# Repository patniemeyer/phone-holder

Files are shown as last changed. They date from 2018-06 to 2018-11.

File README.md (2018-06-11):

# OpenSCAD Tesla Model 3 Cup holder mount for iPhone X
_Pat Niemeyer (pat@pat.net), https://github.com/patniemeyer/phone-holder)

<table>
  <tr>
    <th>
      
    </th>
    <th>
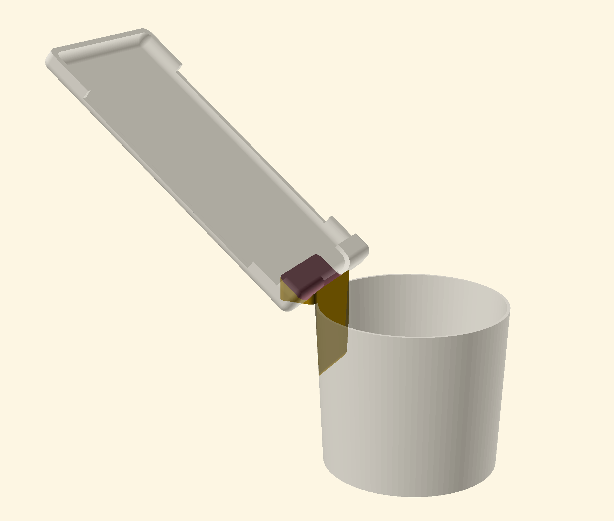
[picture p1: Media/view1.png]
      
    </th>
  </tr>
</table>

This is a simple OpenSCAD phone holder that mounts an iPhone X in a Tesla Model cup holder.

## Warning: 
The rubber lining of the cup holder and the plastic surface of the center console are easily scratched.
If you print this phone holder yourself please go over it with some sandpaper to remove any unexpected bumps or
rough spots before using it in your car!  

## Printing the parts 

The STL folder contains the STL cup-holder.stl file along with some other phone mounts from this project.

I was able to print this easily with only supports on the center connector area as shown here:
</p>
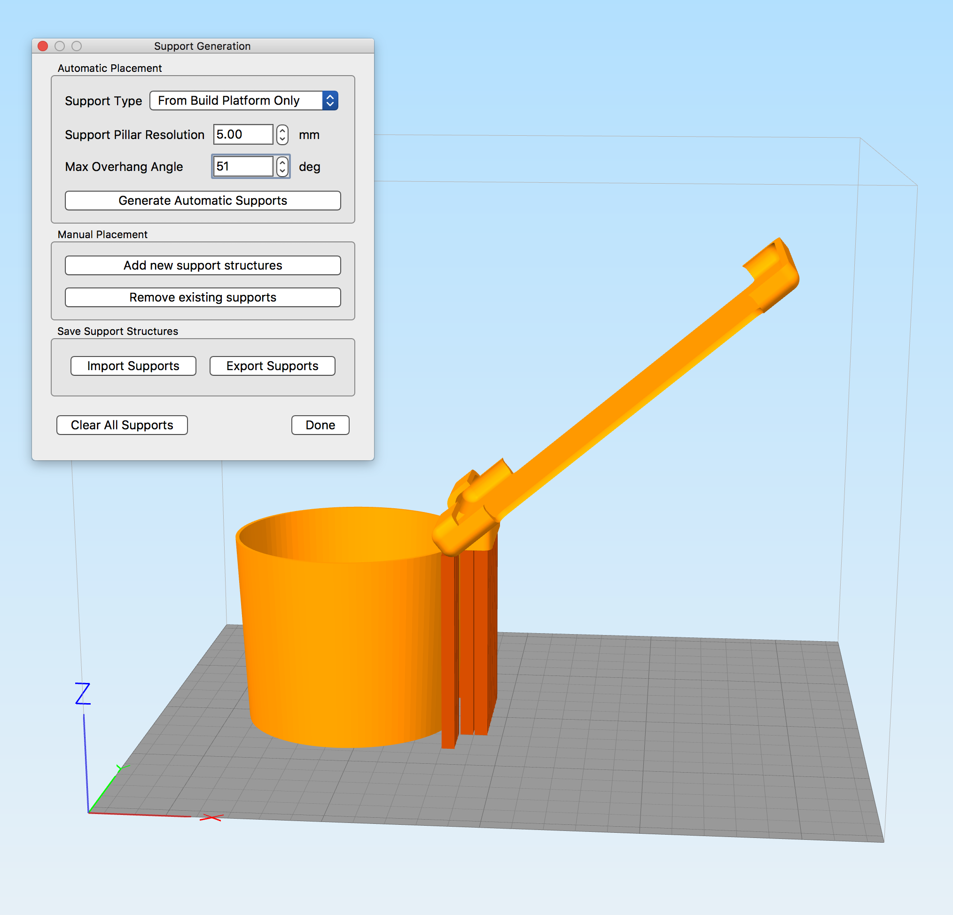
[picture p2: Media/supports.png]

</p>

An obvious improvement would be to make this printable in two sections for those who cannot print it in a single pass.

## Issues

The first version of this was thinner and I found that the PLA softened when the car was in direct sunlight, causing 
it to droop a bit.  I will continue to refine this as I see how the new one holds up.  If you wish to experiment, just
change the `phone_thickness` parameter in the scad file.

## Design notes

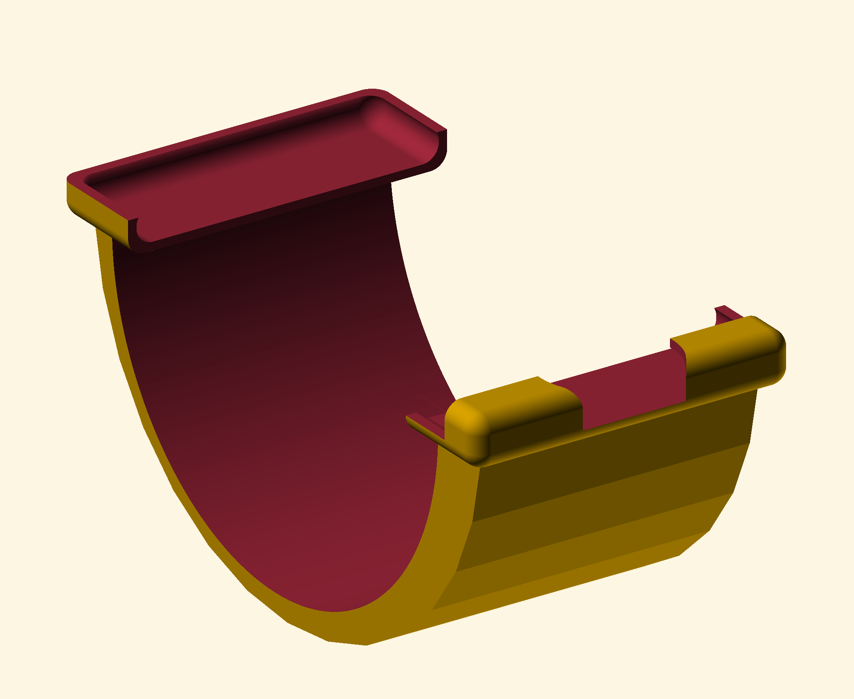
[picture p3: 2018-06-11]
Media/Screen Shot 2018-02-23 at 7.23.17 PM.png

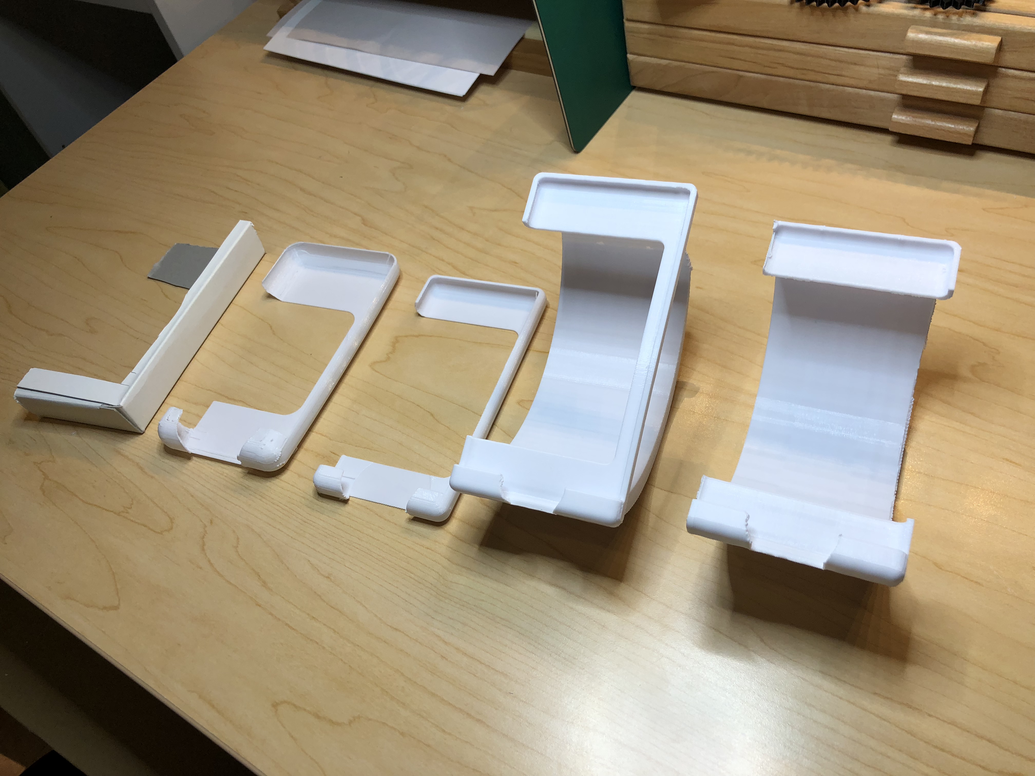
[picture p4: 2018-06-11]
Media/prototypes1.jpg

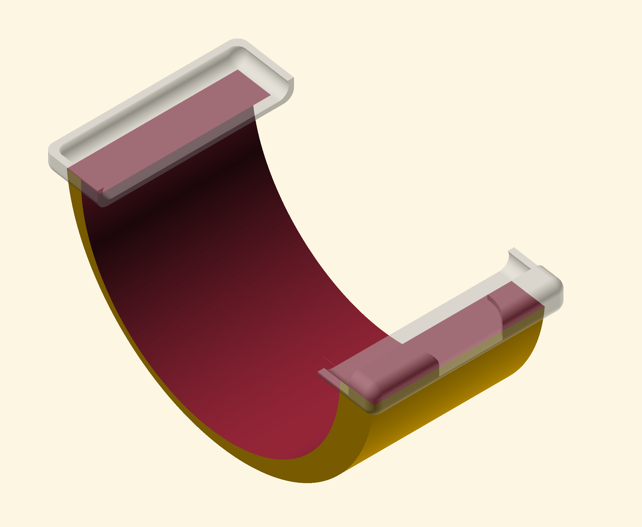
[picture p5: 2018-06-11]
Media/curved1.png

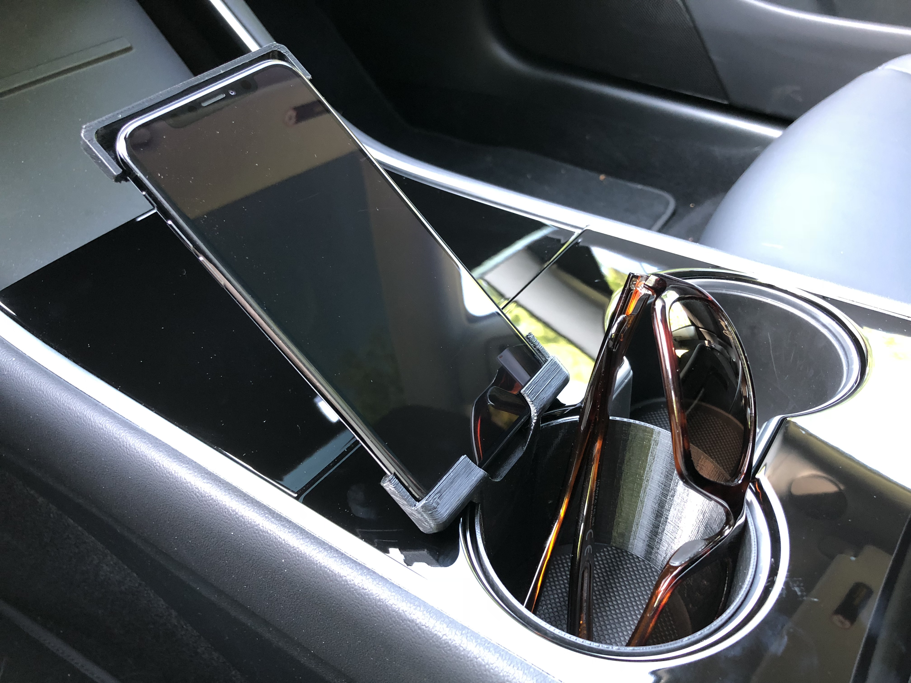
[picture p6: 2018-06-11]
Media/phone-holder-car.jpg

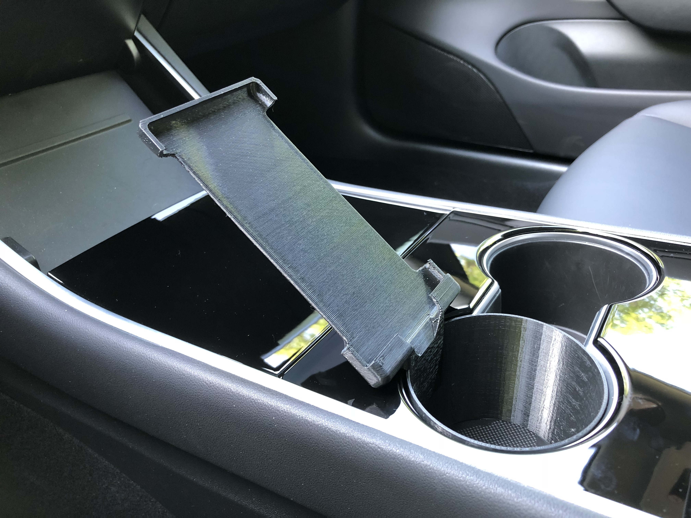
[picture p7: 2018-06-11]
Media/phone-holder-car1.jpg

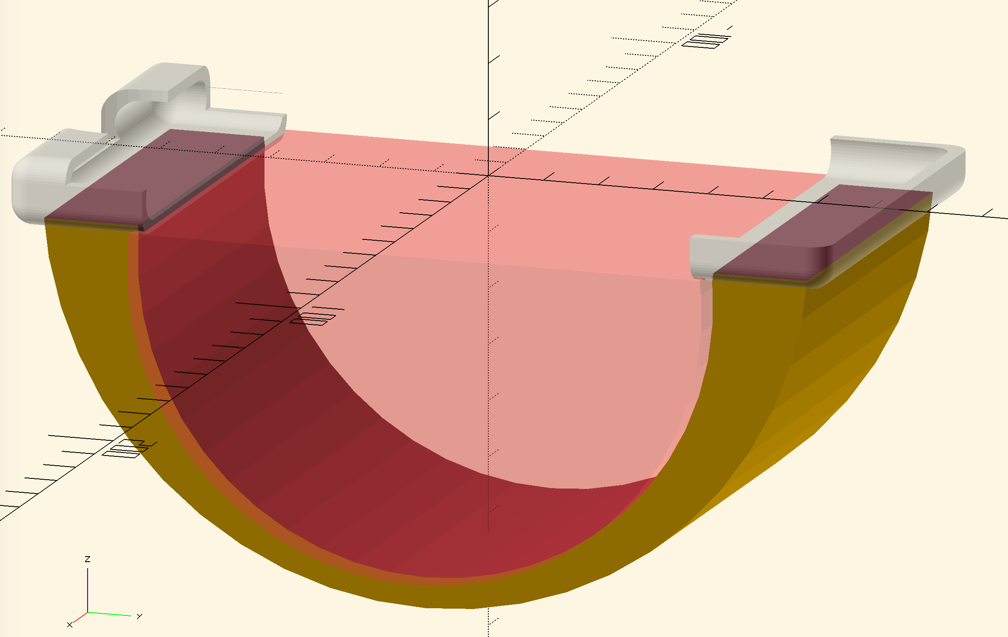
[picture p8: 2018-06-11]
Media/facets.png

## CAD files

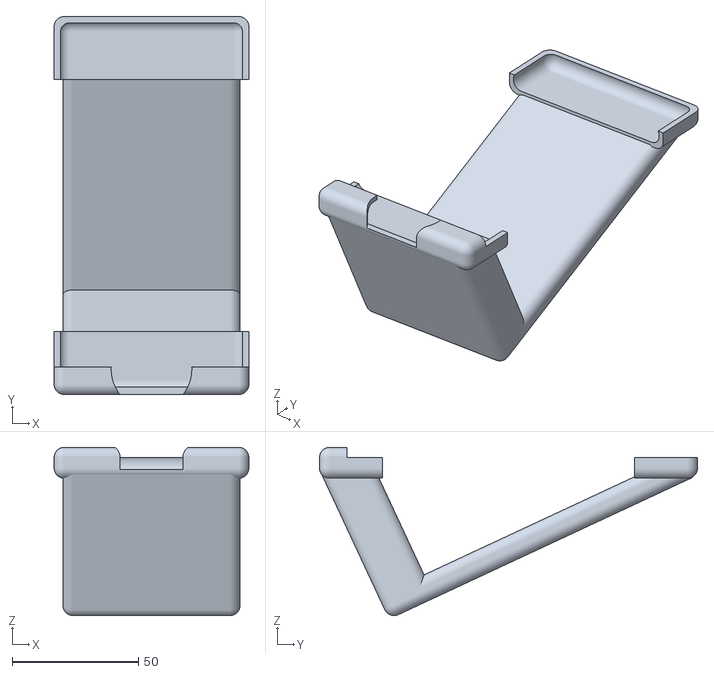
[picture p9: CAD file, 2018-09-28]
STL/iPhoneX/phone-wall-stand.stl
77.2 x 149.9 x 66.7

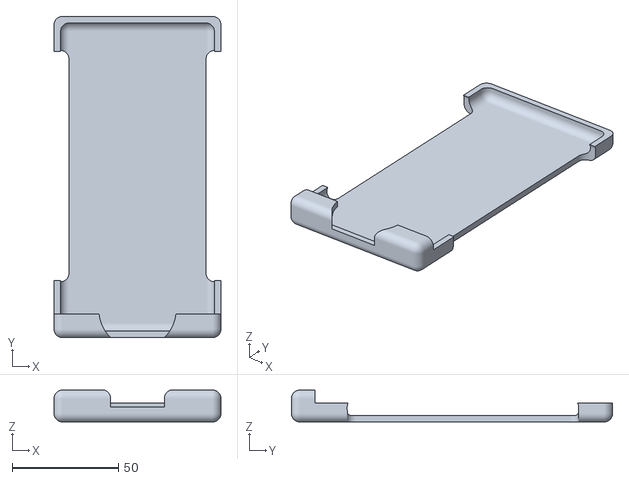
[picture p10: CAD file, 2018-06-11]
STL/iPhoneX/phone-base2.stl
78.5 x 151.0 x 15.0

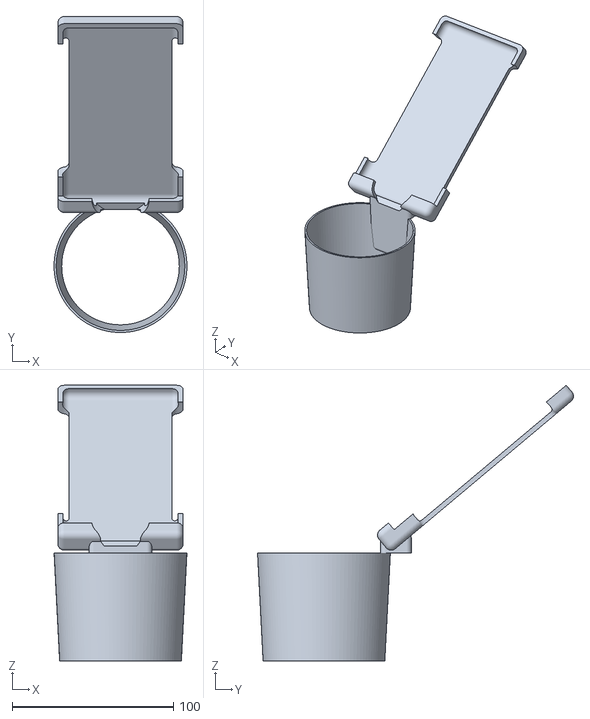
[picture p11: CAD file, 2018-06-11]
STL/iPhoneX/cup-holder.stl
82.5 x 196.2 x 171.0

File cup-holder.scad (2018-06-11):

///
/// Tesla Model 3 iPhone X cup holder phone cradle.
/// Part of https://github.com/patniemeyer/phone-holder
/// By Pat Niemeyer (pat@pat.net)
///

include <rounded.scad>;

//$fn=100; // Note: Increase $fn for final render.
$fn=30;

O=0.1; // negligible offset
OT=0.2; // negligible thickness

layer_width=0.44;

// Phone 
phone_width_physical=71.75;  // The volume the phone will occupy
phone_height_physical=144.5;
phone_depth_physical=9.0; 
phone_thickness=3.0; // case thickness
phone_r=4; // curve radius, limited by phone depth
phone_cutout_height=phone_height_physical*3/4;
phone_cutout_height_start=16.0; // how far down from the top do we start
phone_cutout_side_width=2; // used if cutout_sides is true
phone_cradle_height=11; // The bottom area by the home button cutout

// Phone derived
phone_height=phone_height_physical+2*phone_thickness;
phone_depth=phone_depth_physical+2*phone_thickness;
phone_width=phone_width_physical+2*phone_thickness;

// Cup
cup_thickness=3*layer_width;
cup_diam_top=82.5; 
cup_diam_bottom=75.6; 
cup_depth = 67.0; 

// Connector
con_width=phone_width/2;
con_height=19.0;
con_depth=cup_depth*3/4;
con_r = 3;
con_center_z = 12.0; // z height above cup holder
con_center_y = 13.0; // y offset behind cup holder
con_angle = 40; 


module rotate_about_pt(v, pt) translate(pt) rotate(v) translate(-pt) children(); 

// Cutout full width, depth to back thickness with specified height and offset
module cutout_full_width() {
    translate([0, phone_height/2 -phone_cutout_height/2 - phone_cutout_height_start, 0])
    roundedBox([phone_width+10, phone_cutout_height, phone_depth], phone_r, center=true);
}

module cutout_button() {
    translate([0,-phone_height_physical/2+10,phone_thickness+1])
      cylinder(h=phone_depth_physical, d=phone_width_physical/2, center=true);
}

// Phone body
module phone_body(cutout_sides=true)
{
  difference() {
    // box outside, inside
    roundedBox([phone_width,phone_height,phone_depth], phone_r, center=true);
    roundedBox([phone_width_physical,phone_height_physical,phone_depth_physical], phone_r, center=true);

    if (cutout_sides) {
      // Note: -phone_r helps here because we are cutting with the rounded edge but we want a more vertical slice
      translate([-phone_width+phone_cutout_side_width,0,-phone_thickness]) 
        cutout_full_width();
      translate([phone_width-phone_cutout_side_width,0,-phone_thickness])
        cutout_full_width();
    } else {
      cutout_full_width();
    }

    // shave top
    extra_depth=0.5;
    translate([0,phone_cradle_height,phone_depth-phone_thickness*2+extra_depth])
      cube([phone_width+2,phone_height,phone_depth], center=true);

    cutout_button();
  }
}

module cupInside() {
    cylinder(h=cup_depth+.1, 
      d1=cup_diam_bottom-2*cup_thickness, 
      d2=cup_diam_top-2*cup_thickness, 
      center=true);
}
module cupOutside(expand_outside=0) {
    cylinder(h=cup_depth, 
      d1=cup_diam_bottom+expand_outside, 
      d2=cup_diam_top+expand_outside, 
      center=true);
}
module cup(expand_outside=0) {
  //minkowski() {
    difference() {
      cupOutside(expand_outside);
      cupInside();
    }
    //sphere(r=phone_r, center=true);
  //}
}

// The center of the connector 
connector_location = [0, 
  cup_diam_top/2-con_height/2 + con_center_y, 
  cup_depth/2-con_depth/2 + con_center_z
];

module connector() 
{
  difference() 
  {
    // core box for connector
    translate(connector_location)
      roundedBox([con_width, con_height, con_depth], con_r, center=true);

    // remove the volume outside the cup
    difference() {
      cupOutside(expand_outside=50.0);
      cupOutside(expand_outside=0.0);
    }

    // remove the phone holder
    hull() positioned_phone_body();

    phone_position() cutout_button();
  }
}

module phone_position() {
  translate([0,phone_height/2+cup_diam_top/2,0])
  translate([0,0,cup_depth/2+phone_depth/2])
  rotate_about_pt([con_angle,0,0], [0,-phone_height/2,-phone_depth/2])
    children();
}

module positioned_phone_body() {
  phone_position() phone_body();
}

positioned_phone_body();
connector();
cup();
//phone_body();

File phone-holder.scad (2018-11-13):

///
/// Experiment with rounded iPhone X phone stand.
/// Part of https://github.com/patniemeyer/phone-holder
/// By Pat Niemeyer (pat@pat.net)
///
/// (See improved phone base in the cup-holder.scad file.)
///

include <rounded.scad>;

$fn=50;
width=3*25.4 + 1.0;
height=6*25.4 - 2.5;
depth=12.25;
thickness=1.5;
r=4;
cutoutHeight=height*2/3;

// Phone body
module phone_body()
{
  difference() {
    // box outside, inside
    roundedBox([width,height,depth], r, center=true);
    roundedBox([width-thickness,height-thickness,depth-thickness], r, center=true);

    // Cutout - left side only
    //translate([-width/8,0,0])
      //roundedBox([width, height*2/3, depth*2], r, center=true);

    // Cutout - full width, full depth
    //cube([width+2, cutoutHeight, depth+2], center=true);

    // Cutout - full width, half depth
    translate([0,0,thickness])
    cube([width+2, cutoutHeight, depth], center=true);

    // open the left side of the base
    //translate([-width/2,-49,thickness])
      //cube([5, 30, depth], center=true);

    // shave top
    translate([-0,11,depth-thickness])
      cube([width+2,height,depth], center=true);

    // home button opening
    translate([0,-height/2+10,thickness])
      cylinder(h=depth+1, d=r*8.0, center=true);
  }
}

// Base body
module base_body() {
  translate([0,0,0.9]) // position the base against the phone
  difference() 
  {
    // params
    outerInset = 5;
    innerInset = 5;

    // calcs
    baseHeight=(height-cutoutHeight)/2; // height of the base where it touches the phone body
    dout=height-outerInset*2; // outer diamter
    din=dout-baseHeight*2+outerInset*2+innerInset*2; // inner diamter

    // Outer curve
    // Note: deliberately experimenting with low $fn to make this faceted.
    rotate(a=[0,90,0]) 
      cylinder($fn=30,h=width-2*outerInset, d=dout, center=true);

    // inner curve
    rotate(a=[0,90,0]) 
      cylinder(h=width+2, d=din, center=true);

    // scoop out arch
    {
      // params
      archDout=dout*0.84; // radius of the scoop out curve
      archOffset=-height*0.030;
      archThin=5.0; // thickness of the thinnest part of the arch (if centered :))

      // calcs
      sdown=(dout/2-archDout/2)-archThin;

      difference() {
        translate([0,-archOffset,-sdown])
          rotate(a=[0,90,0]) 
            cylinder(h=width+2, d=archDout, center=true);

        // Cut off below phone body
        translate([0,0,height/2-depth/2]) cube([width+4, height+2, height], center=true);
      }
    }

    // Cut off at plane of phone body
    translate([0,0,height/2-depth/2]) cube([width+2, height+2, height], center=true);
  }
}

phone_body();
base_body();

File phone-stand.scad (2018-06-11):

///
/// Quick and dirty iPhone X wall holder
/// Part of https://github.com/patniemeyer/phone-holder
/// By Pat Niemeyer (pat@pat.net)
///
/// (See improved phone base in the cup-holder.scad file.)
///

include <rounded.scad>;

$fn=50;
width=3*25.4 + 1.0;
height=6*25.4 - 2.5;
depth=12.25;
thickness=4.0;
r=4;

cutoutHeight=height*2/3;

module phone_body()
{
  difference() {
    // box outside, inside
    roundedBox([width,height,depth], r, center=true);
    roundedBox([width-thickness,height-thickness,depth-thickness], r, center=true);

    // main cutout - left side only
    //translate([-width/8,0,0])
      //roundedBox([width, height*2/3, depth*2], r, center=true);

    // main cutout - full width
    cube([width+2, cutoutHeight, depth+2], center=true);

    // open the left side of the base
    translate([-width/2,-49,thickness])
      cube([6, 30, depth], center=true);

    // shave top
    translate([-0,11,depth-thickness])
      cube([width+2,height,depth], center=true);

    // home button opening
    translate([0,-height/2+10,thickness])
      cylinder(h=depth+1, d=r*8.0, center=true);
  }
}


module stand_base() {
  baseHeightInset = 2.60;
  baseWidthInset = 7;
  baseHeight = 20;
  baseDepth=110;
  baseDepthOffset = 0;
  difference() {
    translate([0,-height/2+baseHeight/2+baseHeightInset, -depth/2+baseDepthOffset])
      rotate(a=[25,0,0]) 
        roundedBox([width-baseWidthInset, baseHeight, baseDepth], r, center=true);

    // Cut off below phone body
    offset = 2.0;
    translate([0,0,height/2-depth/2+offset]) cube([width+4, height*2, height], center=true);
  }

  difference() {
    translate([0,16,-25])
      rotate(a=[90+25,0,0]) 
        translate([0,-1.7,5])
        roundedBox([width-baseWidthInset, baseHeight/2, baseDepth+baseHeight+6], r, center=true);

    // Cut off below phone body
    offset = 2.0;
    translate([0,0,height/2-depth/2+offset]) cube([width+4, height*2, height], center=true);

    //translate([0,-33,-41]) rotate(a=[0,90,0]) cylinder(h=width, d=18.0, center=true);
  }

}

phone_body();
stand_base();

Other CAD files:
phone-cup-holder.scad
rounded.scad

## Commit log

2018-09-28 Added iPhone Xs Max sizing.
    [cup-holder-XsMax.stl, phone-cup-holder.scad, phone-holder.scad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]
2018-10-24 Moved models into folders for iPhoneX, iPhoneXsMax sizes.
    [cup-holder-XsMaxFinal.stl, cup-holder.stl, phone-base2.stl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]
2018-11-13 Fix missing thickness.
    [phone-holder.scad]
